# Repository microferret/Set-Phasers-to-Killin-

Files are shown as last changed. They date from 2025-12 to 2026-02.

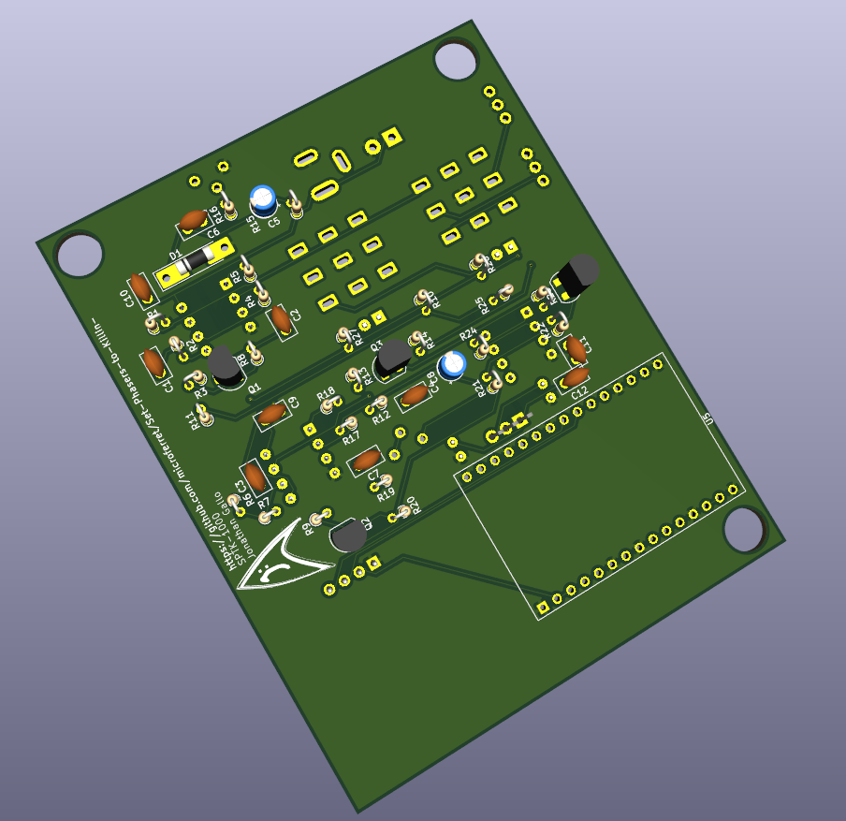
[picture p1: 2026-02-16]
Customshift_Phaser/Pasted image 20260216174914.png

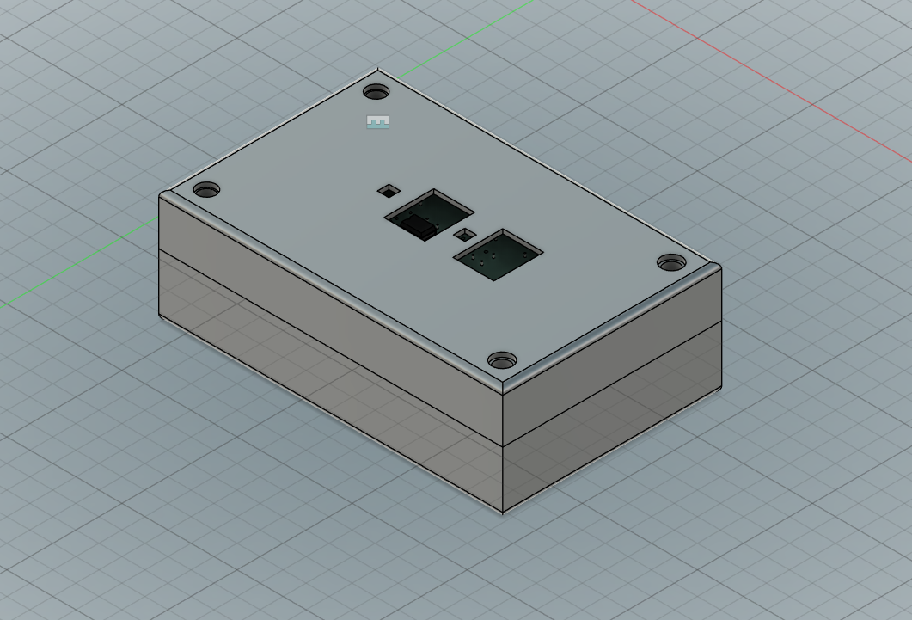
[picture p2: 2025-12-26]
Customshift_Phaser/Pasted image 20251226013236.png

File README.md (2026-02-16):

Within the world of electric instruments (particularly that of the electric guitar and bass), there are a wealth of ways to modify your instrument's sound. This is typically done via the use of foot-controlled effects pedals. One type of effect pedal, the "Phaser" pedal, shifts the phase of the output signal sent to a instrument amplifier. This creates a distinct sound that can be very desirable in certain applications. This type of effect pedal is what I have created a custom design for. My pedal will essentially resemble a MXR Phase 45 pedal in terms of architecture but will also have a togglable extra phase shifting network to shift the phase of the output by an extra amount.

Below is a screenshot of the schematic for my project:


Below is a screenshot of the PCB layout:


Below are screenshots of the a 3D render of the PCB:



See included Obsidian file for design process documentation.
I have an explaination of how the device works in the documentation as well. Below is the source I used to help me with this project:
https://barbarach.com/breadboard-a-simple-phaser/

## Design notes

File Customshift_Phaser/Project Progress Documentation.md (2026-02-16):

### Slight aside
Prior to official documentation, this project was an undocumented one-off that I created without any real intention to manufacture a physical product, so, naturally, there are going to be some gaps in the progress record.

I'll be transparent when I can't verify the exact amount of time spent on a portion of this project.

### Phase 1: How does a Phaser work?
The first step in this project was to determine how exactly commercial phasers work so I could build one myself. To do this, I followed a tutorial with a very helpful sample schematic included (https://barbarach.com/breadboard-a-simple-phaser/).

### Phase 2: KiCAD Schematic
After reading about the phase shifting networks required to build a phaser pedal, I was able modify the original design to meet my specifications. Below is the first iteration of my phaser pedal schematic:
![[Screenshot 2025-10-25 185339.png]]

Afterward, I realized I had made a mistake regarding the switched phase and made a correction. Below is a screenshot of the final iteration of the schematic:
![[Pasted image 20251223214823.png]]

A good portion of making the schematic was completed on my off time at school during the aforementioned period when I was only doing this project for fun. When the Blueprint started, I poured more time into this schematic. So at this point, about 3-4 hours of labor was contributed to the project. 
### Phase 3: PCB Layout
Now that the  schematic has been finished, it is now a matter of creating the PCB layout. To manufacture the physical product, I will need to export the Gerber files and order the PCBs to be milled using a milling service such as PCB-Way or JLCPCB (however, the manufacturing process is out of the scope of this design documentation). 
Below is a screenshot of the final iteration of the PCB layout, complete with all footprints, decals, edges, etc.:
![[Pasted image 20251223214937.png]]
### Phase 4: Enclosure Design
I exported the PCB model from KiCAD as a step file and uploaded it into a Fusion 360 project folder that I created for this project. Below is a screenshot of the fully assembled enclosure.
![[Pasted image 20251226013236.png]]
### PCB Corrections
![[Pasted image 20251226221127.png]]
I decided to optimize my board further by adding a copper layer for ground, reducing the amount of traces needed. I had neglected to do this earlier, and only recently realized my optimization mistake. 

By this time, I have put approximately 8-10 hours of labor over a period of 2-3 months working on-and-off.

Later, I cut down the size of the board and added an OLED screen that can be programmed to monitor the output waveform of the phaser.

![[Screenshot 2026-02-16 173127.png]]
![[Screenshot 2026-02-16 173155.png]]
![[Screenshot 2026-02-16 173225.png]]
![[Pasted image 20260216174914.png]]

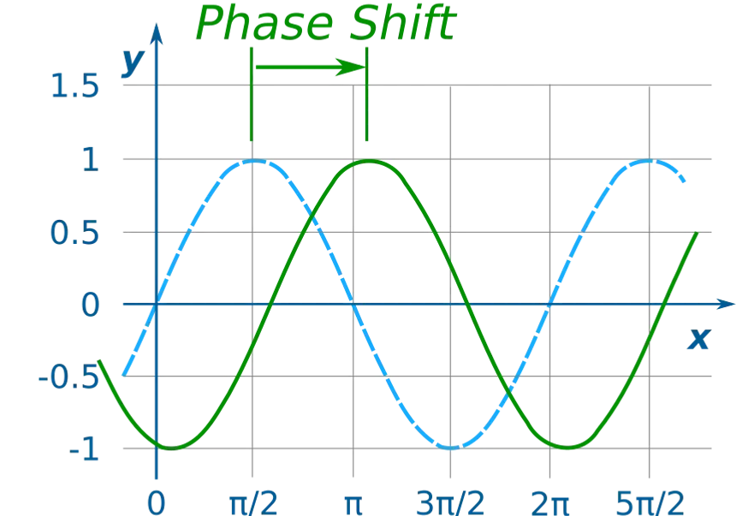
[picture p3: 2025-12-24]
Customshift_Phaser/Pasted image 20251025191522.png

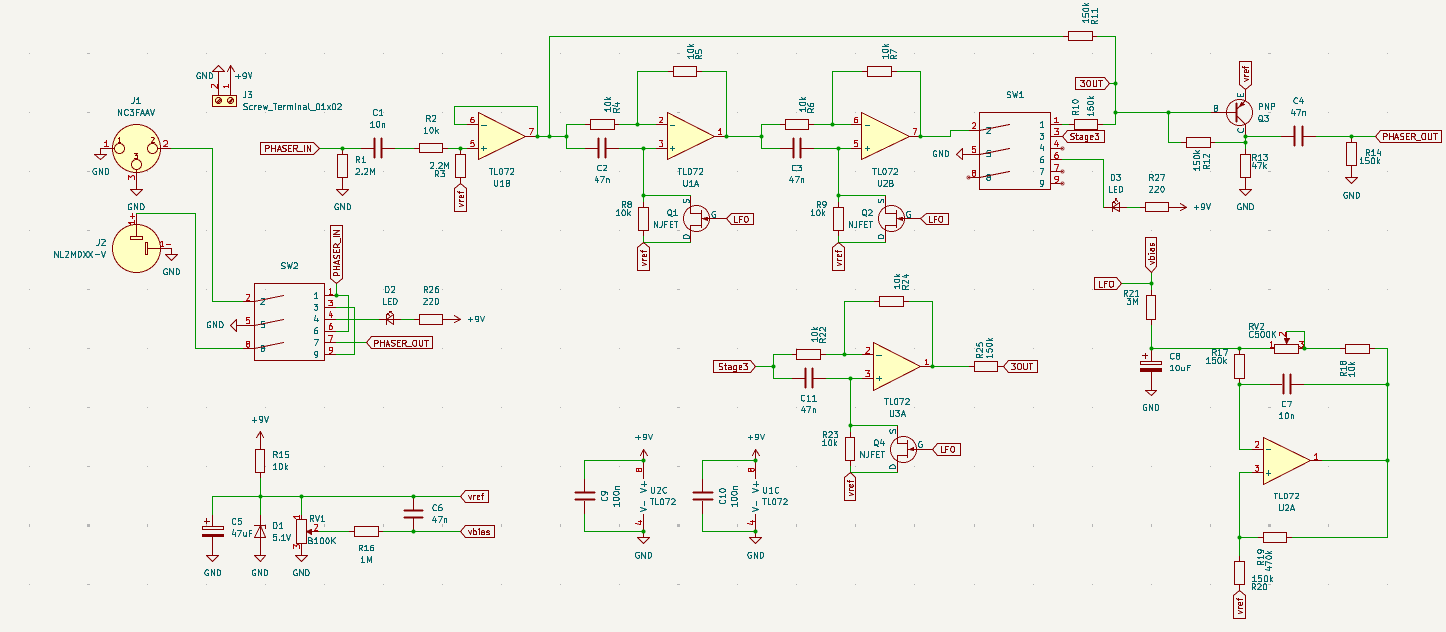
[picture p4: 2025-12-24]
Customshift_Phaser/Screenshot 2025-10-25 185339.png

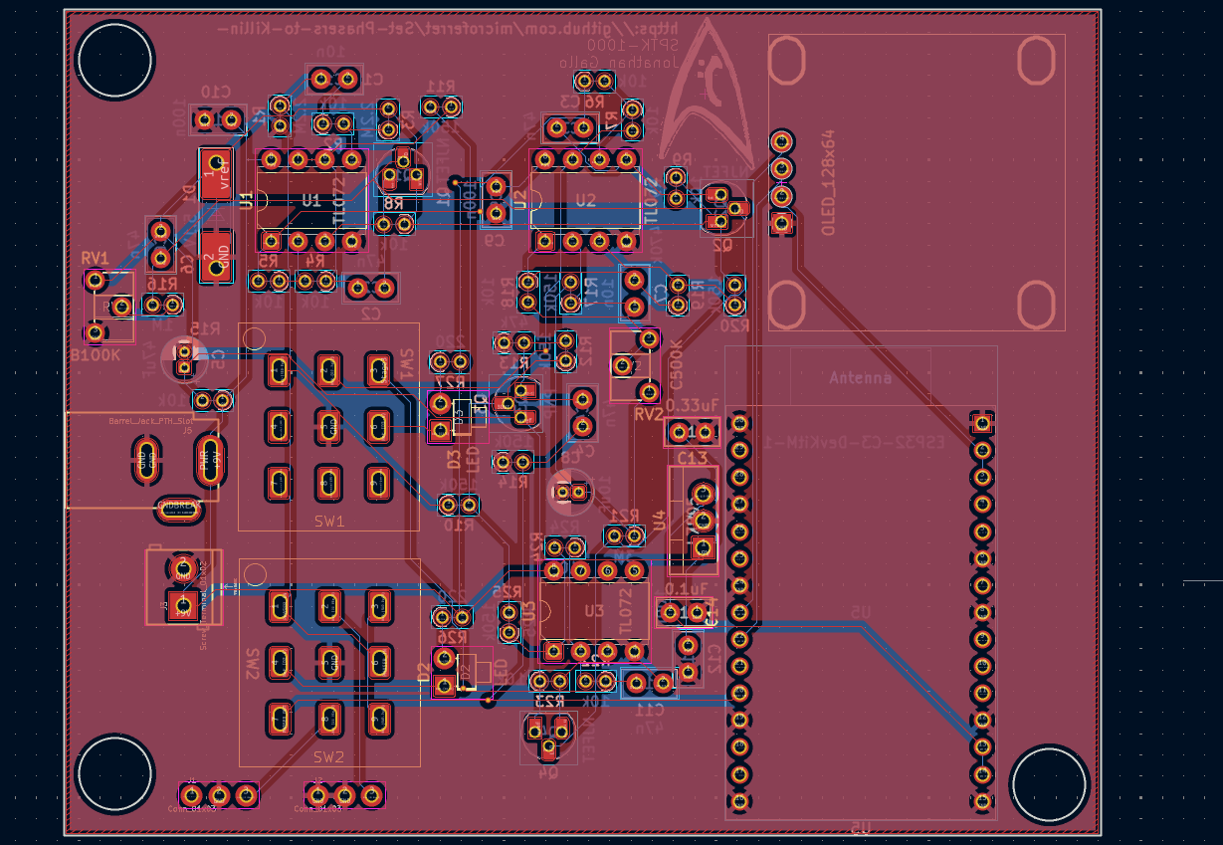
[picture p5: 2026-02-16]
Customshift_Phaser/Screenshot 2026-02-16 173155.png

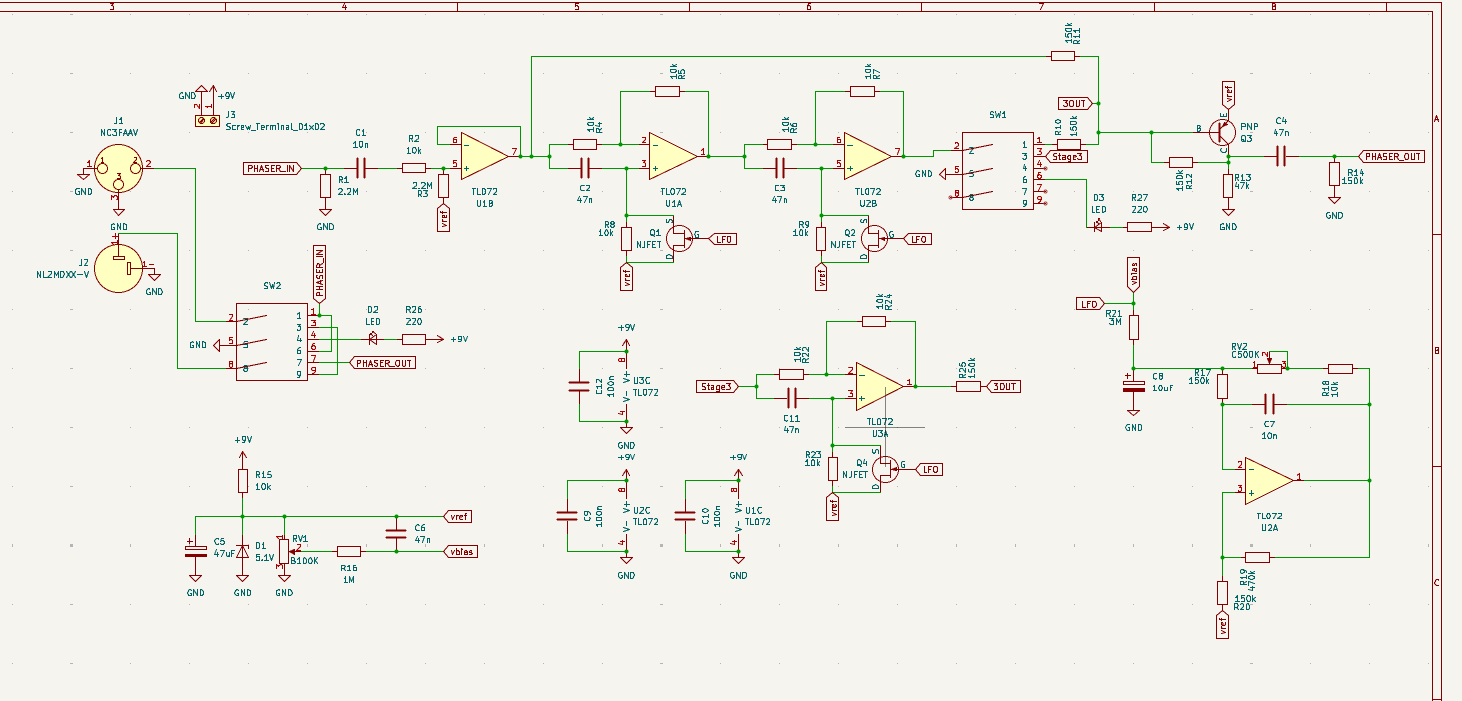
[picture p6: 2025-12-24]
Customshift_Phaser/Pasted image 20251223214823.png

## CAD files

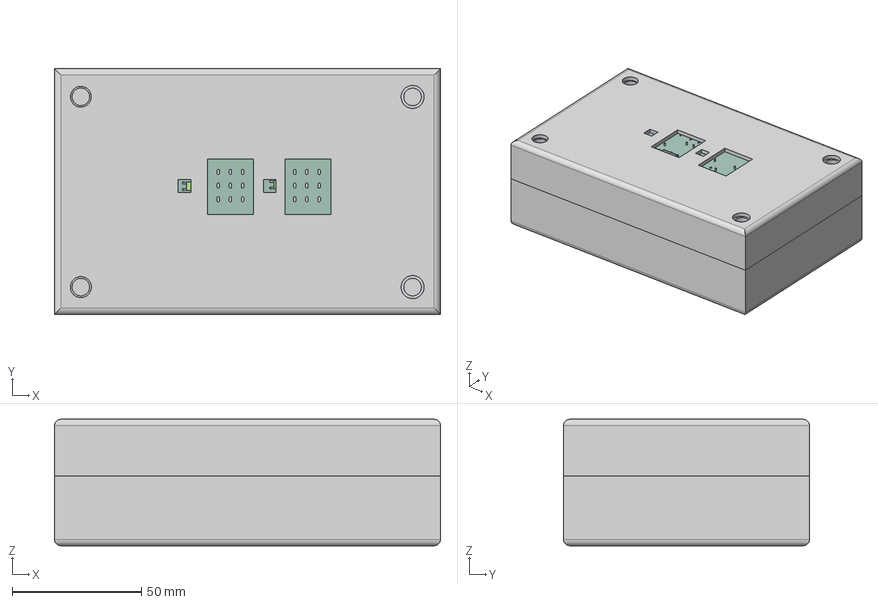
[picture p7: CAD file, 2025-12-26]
phaser_assembly v2.step
149.4 x 95.2 x 49.0 mm
LED_D1.8mm_W1.8mm_H2.4mm_Horizontal_O1.27mm_Z1.6mm x 2
DIP-8_W7.62mm x 3
R_Axial_DIN0309_L9.0mm_D3.2mm_P12.70mm_Horizontal x 27
TO-92L x 4
C_Disc_D5.0mm_W2.5mm_P2.50mm x 10
D_MELF
CP_Radial_D4.0mm_P1.50mm x 2
DE_circuits_PCB
Enclosure_top
Enclosure_Bottom

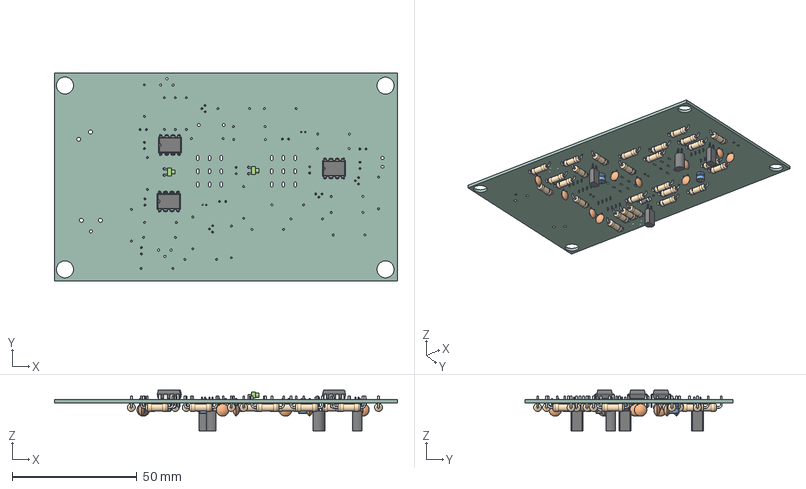
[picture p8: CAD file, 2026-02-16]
DE_circuits.step
137.4 x 83.2 x 16.4 mm
LED_D1.8mm_W1.8mm_H2.4mm_Horizontal_O1.27mm_Z1.6mm x 2
DIP-8_W7.62mm x 3
R_Axial_DIN0309_L9.0mm_D3.2mm_P12.70mm_Horizontal x 27
TO-92L x 4
C_Disc_D5.0mm_W2.5mm_P2.50mm x 10
D_MELF
CP_Radial_D4.0mm_P1.50mm x 2
DE_circuits_PCB

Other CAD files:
phaser_assembly.f3z

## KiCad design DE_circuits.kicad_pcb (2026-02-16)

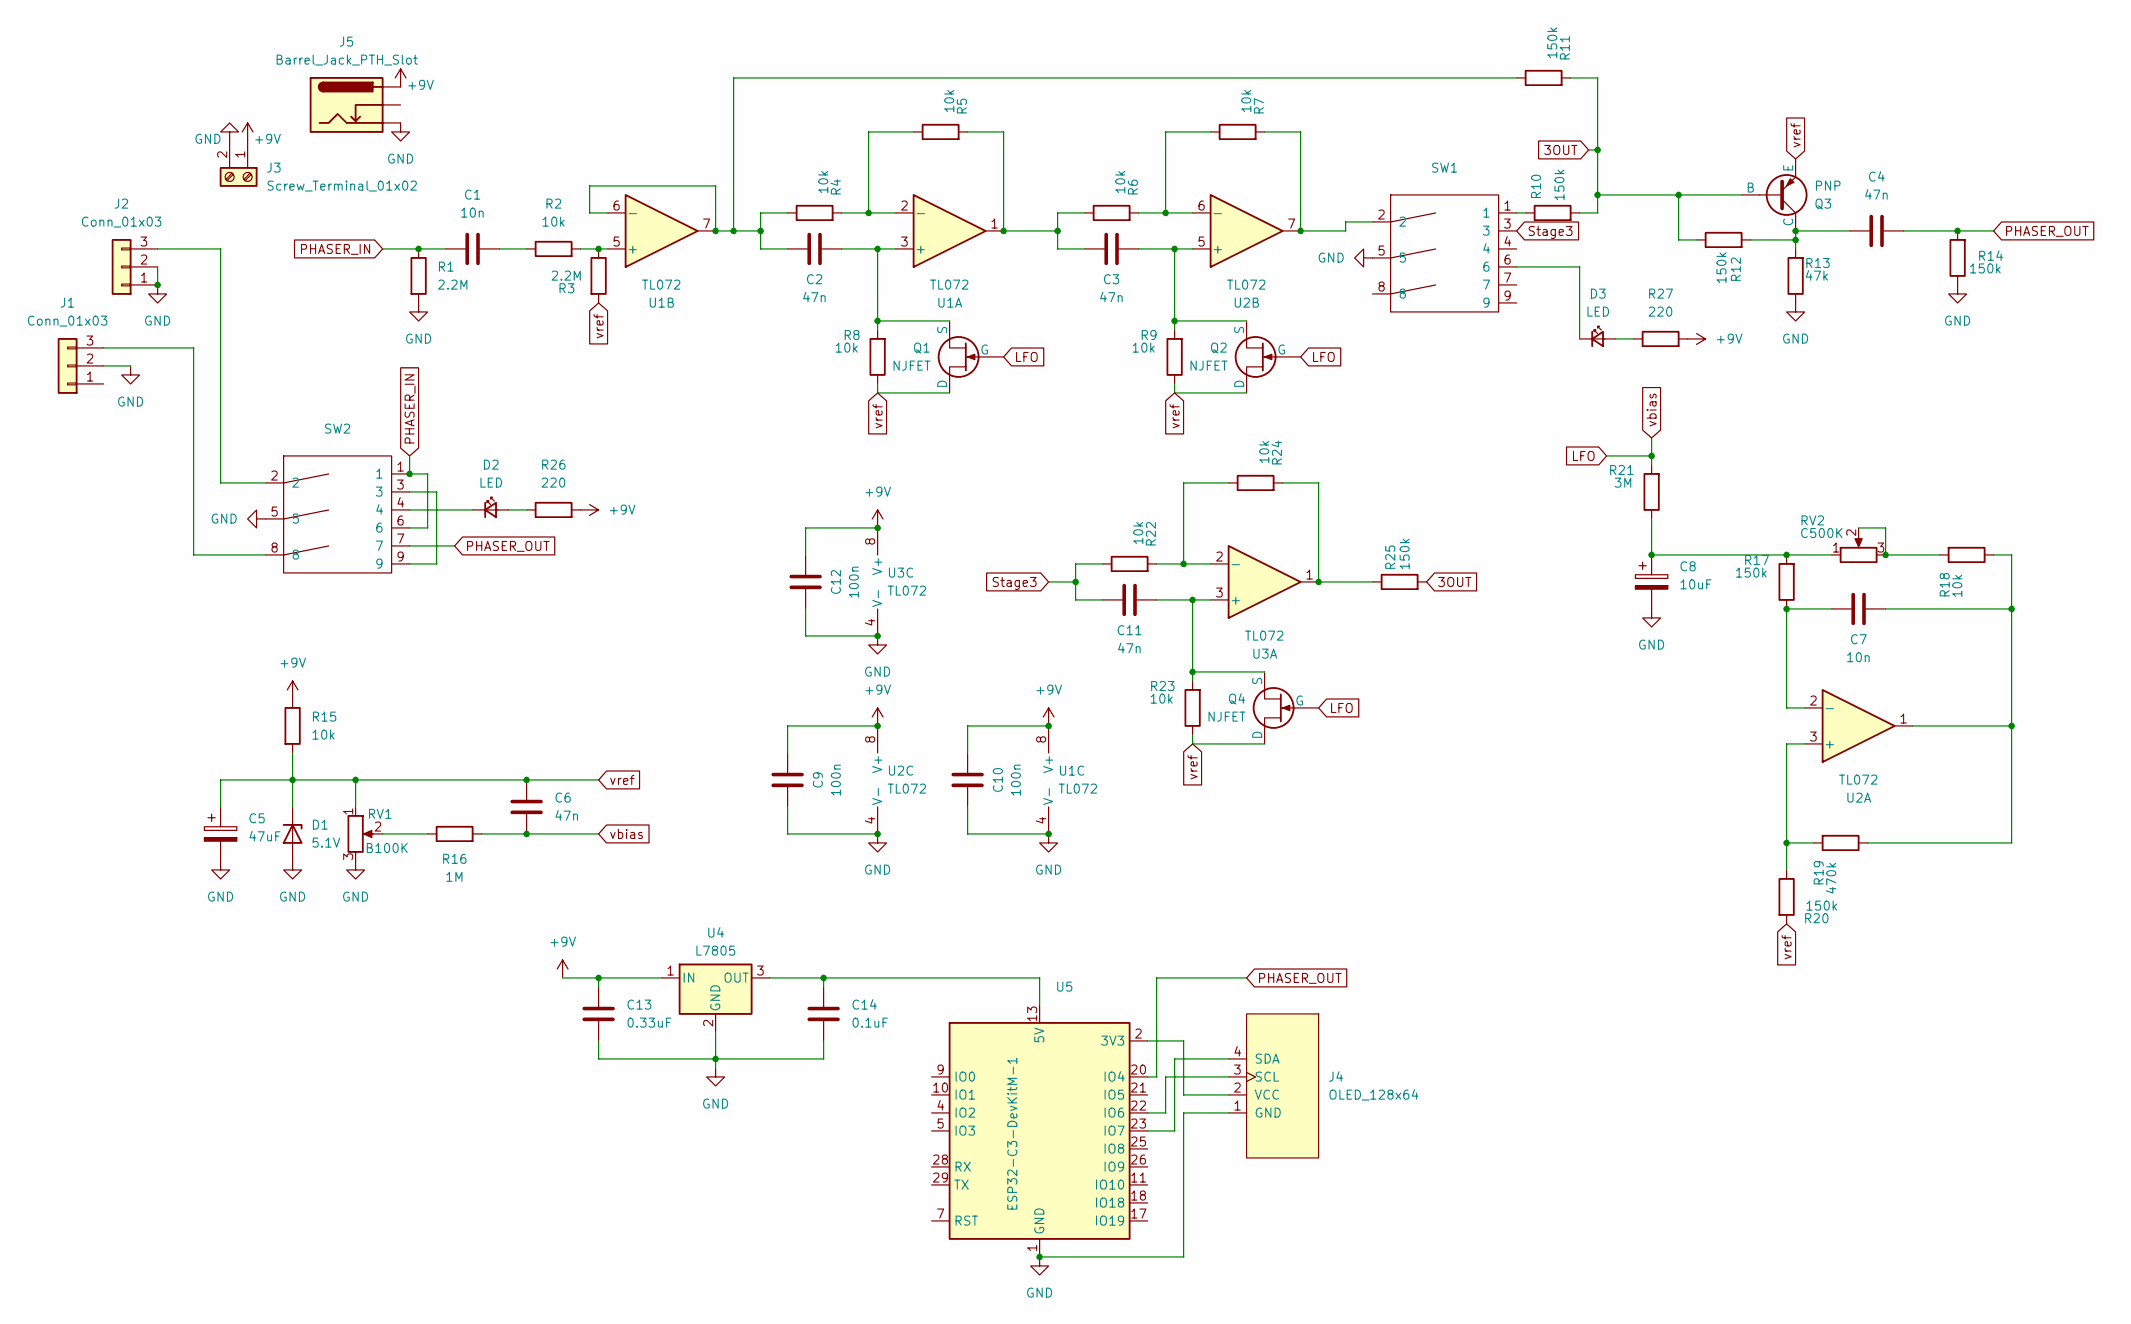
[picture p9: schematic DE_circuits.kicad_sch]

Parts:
C1, C7: 10n; C_Disc_D5.0mm_W2.5mm_P2.50mm
C2, C3, C4, C6, C11: 47n; C_Disc_D5.0mm_W2.5mm_P2.50mm
C5: 47uF; CP_Radial_D4.0mm_P1.50mm
C8: 10uF; CP_Radial_D4.0mm_P1.50mm
C9, C10, C12: 100n; C_Disc_D5.0mm_W2.5mm_P2.50mm
C13: 0.33uF; C_Disc_D5.0mm_W2.5mm_P2.50mm
C14: 0.1uF; C_Disc_D5.0mm_W2.5mm_P2.50mm
D1: 5.1V; D_MELF-RM10_Universal_Handsoldering
D2, D3: LED; LED_D1.8mm_W1.8mm_H2.4mm_Horizontal_O1.27mm_Z1.6mm
J1, J2: Conn_01x03; 1x03_P2.54mm
J3: Screw_Terminal_01x02; ScrewTerminal_1x02_P3.5mm_Horizontal_Black
J4: OLED_128x64
J5: Barrel_Jack_PTH_Slot
Q1, Q2, Q4: NJFET; TO-92L_HandSolder
Q3: PNP; TO-92L_HandSolder
R1, R3: 2.2M; R_Axial_DIN0204_L3.6mm_D1.6mm_P1.90mm_Vertical
R2, R4, R5, R6, R7, R8, R9, R15, R18, R22, R23, R24: 10k; R_Axial_DIN0204_L3.6mm_D1.6mm_P1.90mm_Vertical
R10, R11, R12, R14, R17, R20, R25: 150k; R_Axial_DIN0204_L3.6mm_D1.6mm_P1.90mm_Vertical
R13: 47k; R_Axial_DIN0204_L3.6mm_D1.6mm_P1.90mm_Vertical
R16: 1M; R_Axial_DIN0204_L3.6mm_D1.6mm_P1.90mm_Vertical
R19: 470k; R_Axial_DIN0204_L3.6mm_D1.6mm_P1.90mm_Vertical
R21: 3M; R_Axial_DIN0204_L3.6mm_D1.6mm_P1.90mm_Vertical
R26, R27: 220; R_Axial_DIN0204_L3.6mm_D1.6mm_P1.90mm_Vertical
RV1: B100K; Potentiometer_ACP_CA6-H2,5_Horizontal
RV2: C500K; Potentiometer_ACP_CA6-H2,5_Horizontal
SW1, SW2: Switch-3PDT
U1, U2, U3: TL072; DIP-8_W7.62mm
U4: L7805; TO-220-3_Vertical
U5: ESP32-C3-DevKitM-1

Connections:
3OUT: Q3.2 (B), R10.2, R11.2, R12.1, R25.2
+9V: C9.2, C10.2, C12.2, C13.2, J3.1, J5.PWR, R15.1, R26.2, R27.2, U1.8 (V+), U2.8 (V+), U3.8 (V+), U4.1 (IN)
GND: C5.2, C8.2, C9.1, C10.1, C12.1, C13.1, C14.1, D1.2 (A), J1.2, J2.1, J2.2, J3.2, J4.1 (GND), J5.GND, R1.2, R13.1, R14.1, RV1.3, SW1.5, SW2.5, U1.4 (V-), U2.4 (V-), U3.4 (V-), U4.2 (GND), U5.1 (GND), U5.6 (GND), U5.8 (GND), U5.12 (GND), U5.15 (GND), U5.16 (GND), U5.19 (GND), U5.24 (GND), U5.27 (GND), U5.30 (GND)
LFO: C6.1, Q1.2 (G), Q2.2 (G), Q4.2 (G), R16.2, R21.2
unnamed: C1.2, R2.1
unnamed: C3.1, R5.2, R6.1, U1.1
unnamed: C7.2, R18.1, R19.1, U2.1
unnamed: C8.1, R17.2, R21.1, RV2.1
unnamed: D2.2 (A), R26.1
unnamed: D2.1 (K), SW2.4
unnamed: D3.2 (A), R27.1
unnamed: D3.1 (K), SW1.6
unnamed: J1.3, SW2.8
unnamed: J2.3, SW2.2
unnamed: J4.3 (SCL), U5.22 (IO6)
unnamed: J4.4 (SDA), U5.23 (IO7)
unnamed: J4.2 (VCC), U5.2 (3V3), U5.3 (3V3)
unnamed: C2.2, Q1.3 (S), R8.2, U1.3 (+)
unnamed: C3.2, Q2.3 (S), R9.2, U2.5 (+)
unnamed: C4.1, Q3.1 (C), R12.2, R13.2
unnamed: C11.2, Q4.3 (S), R23.2, U3.3 (+)
unnamed: R7.2, SW1.2, U2.7
unnamed: R10.1, SW1.1
unnamed: R16.1, RV1.2
unnamed: R18.2, RV2.2, RV2.3
unnamed: R24.2, R25.1, U3.1
unnamed: SW2.3, SW2.9
unnamed: R4.2, R5.1, U1.2 (-)
unnamed: R2.2, R3.1, U1.5 (+)
unnamed: C2.1, R4.1, R11.1, U1.6 (-), U1.7
unnamed: R19.2, R20.1, U2.3 (+)
unnamed: C7.1, R17.1, U2.2 (-)
unnamed: R6.2, R7.1, U2.6 (-)
unnamed: R22.2, R24.1, U3.2 (-)
unnamed: C14.2, U4.3 (OUT), U5.13 (5V), U5.14 (5V)
PHASER_IN: C1.1, R1.1, SW2.1, SW2.6
PHASER_OUT: C4.2, R14.2, SW2.7, U5.20 (IO4)
Stage3: C11.1, R22.1, SW1.3
vref: C5.1, C6.2, D1.1 (K), Q1.1 (D), Q2.1 (D), Q3.3 (E), Q4.1 (D), R3.2, R8.1, R9.1, R15.2, R20.2, R23.1, RV1.1

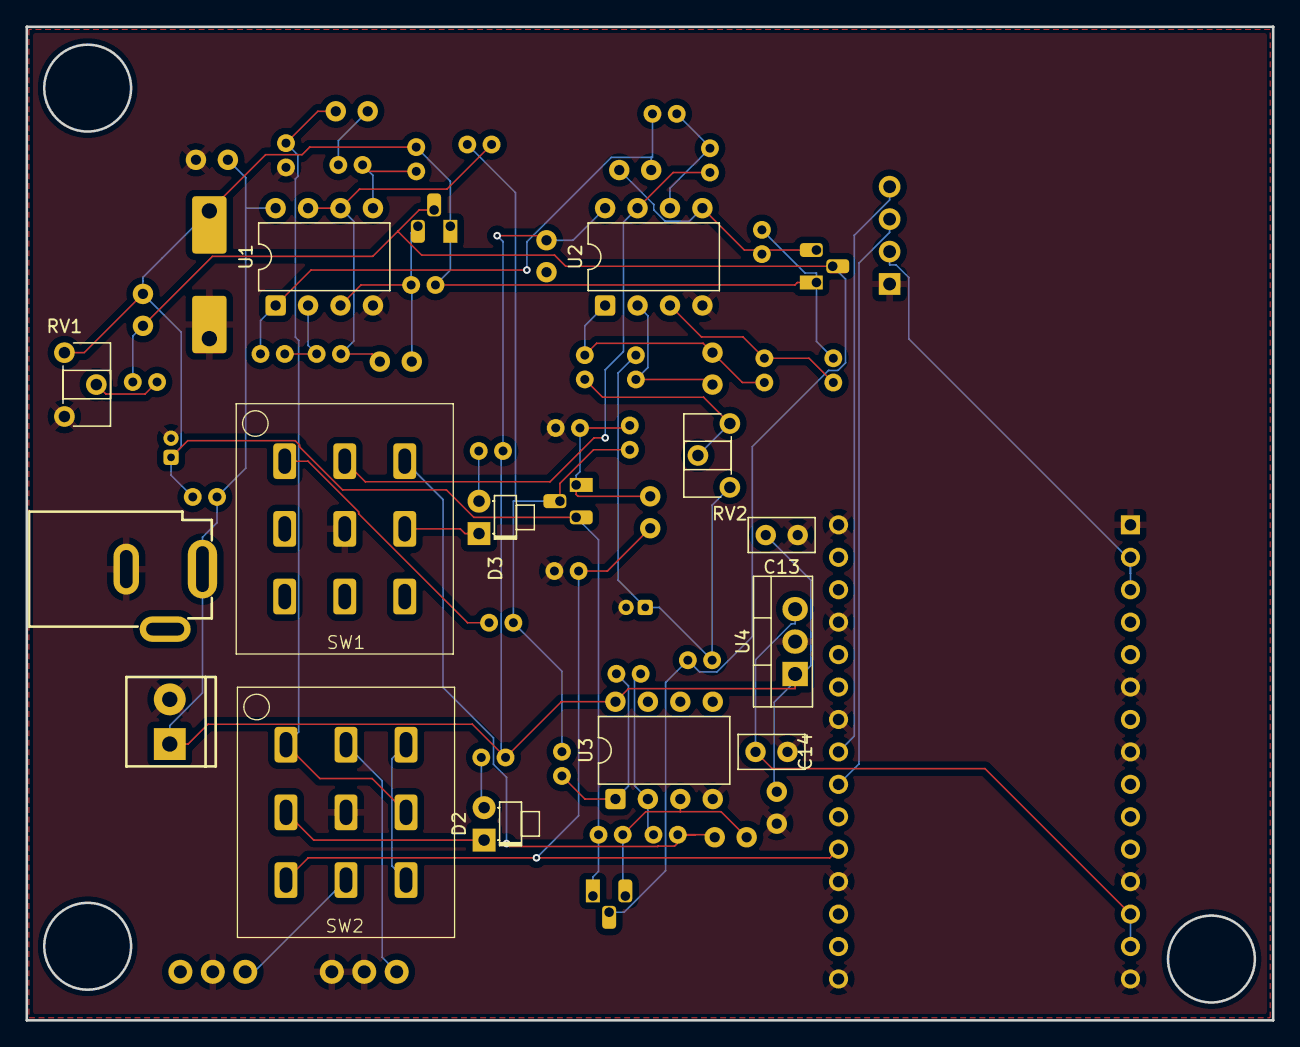
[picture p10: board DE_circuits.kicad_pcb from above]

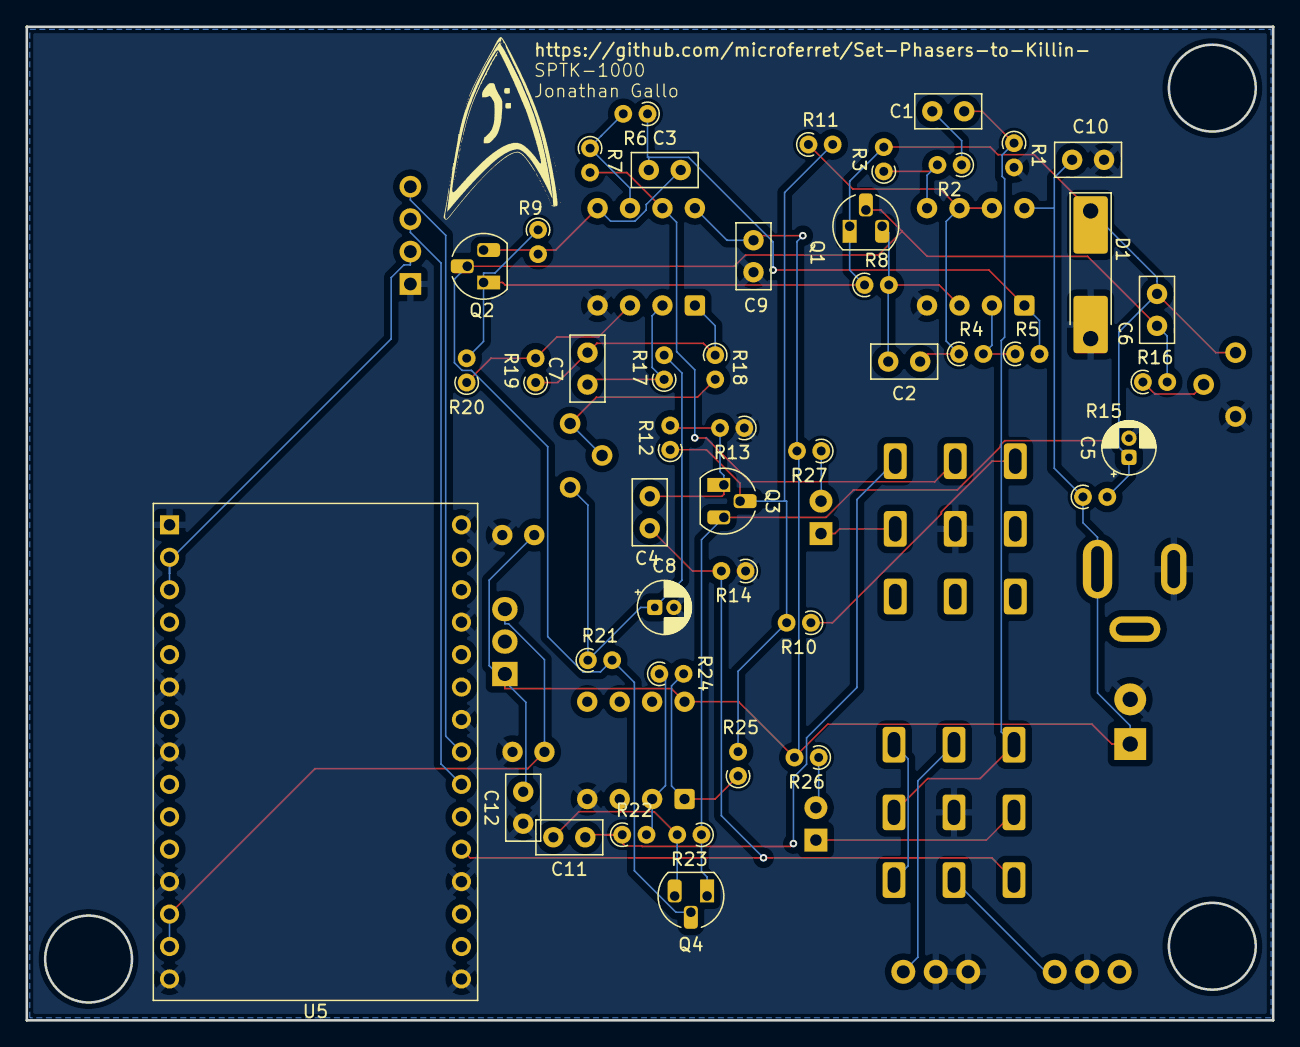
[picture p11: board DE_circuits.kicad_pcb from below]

Board: 2 copper layers, 97.6 x 77.8 mm, 62 parts (45 on the bottom side), 39 nets.

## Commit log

2025-12-24 Add files via upload
    KiCAD Files
    [DE_circuits.kicad_pcb, DE_circuits.kicad_sch]
2025-12-26 Phaser Fusion Assembly
    Fusion files for the Phaser enclosure
    [phaser_assembly v2.step, phaser_assembly.f3z]
2026-02-16 Final Update of PCB
    This is the last iteration of my project unless there is a real serious issue that needs to be rectified.
    [DE_circuits-B_Cu.gbl, DE_circuits-B_Mask.gbs, DE_circuits-B_Paste.gbp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]
